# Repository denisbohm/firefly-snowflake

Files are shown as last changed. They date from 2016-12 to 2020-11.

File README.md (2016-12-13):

# firefly-snowflake
Firefly Design LLC - Snowflake Christmas Ornament

The snowflake is a Christmas tree ornament with RGB LEDs that light up in various ways.  It has a rechargeable battery (via micro USB port) and it is controllable via BLE via a Swift app.

This repository has all the files to create a snowflake Christmas ornament.  This includes 3D mechanical files to create the plastic parts, Eagle schematics & layout for the PCBA, PCBA firmware, and Swift App source files.

To compile the firmware you need the Nordic nRF5 SDK 12 and Firefly Ice Firmware.  On macOS:

    $ git clone https://github.com/denisbohm/firefly-snowflake.git
    $ cd firefly-snowflake/firmware
    $ git clone https://github.com/denisbohm/firefly-ice-firmware.git
    $ curl https://www.nordicsemi.com/eng/nordic/download_resource/54291/51/54256290 -o nRF5_SDK_12.zip
    $ unzip nRF5_SDK_12.zip -d nRF5_SDK_12

See [Firefly Design LLC](http://fireflydesign.com) for information on the open source Firefly Design repositories.

## Copyright and License
Copyright 2016 Firefly Design LLC / Denis Bohm



This work is licensed under [Creative Commons Attribution 4.0 International](https://licensebuttons.net/l/by/4.0/88x31.png).

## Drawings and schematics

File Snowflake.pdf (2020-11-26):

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

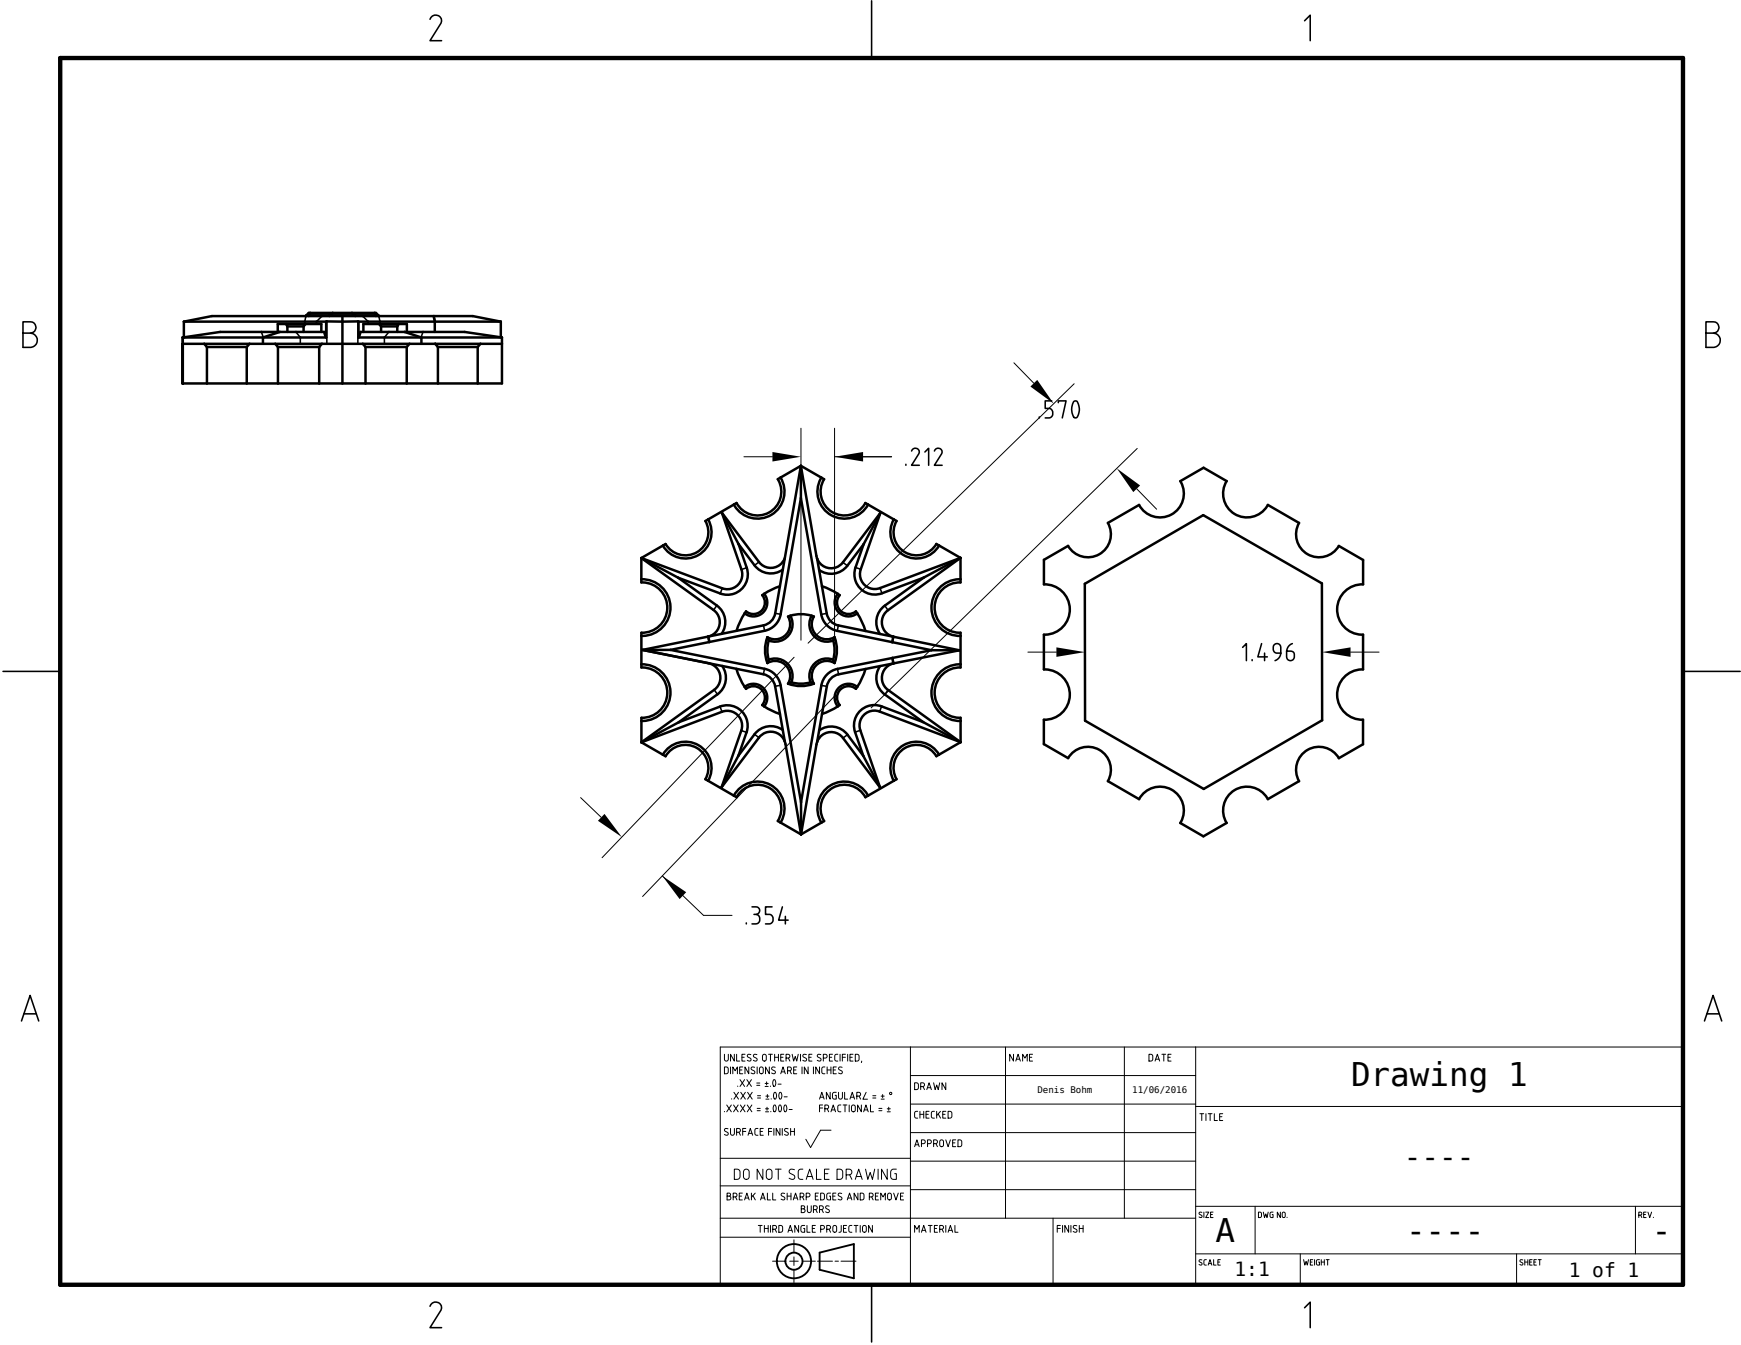
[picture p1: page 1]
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

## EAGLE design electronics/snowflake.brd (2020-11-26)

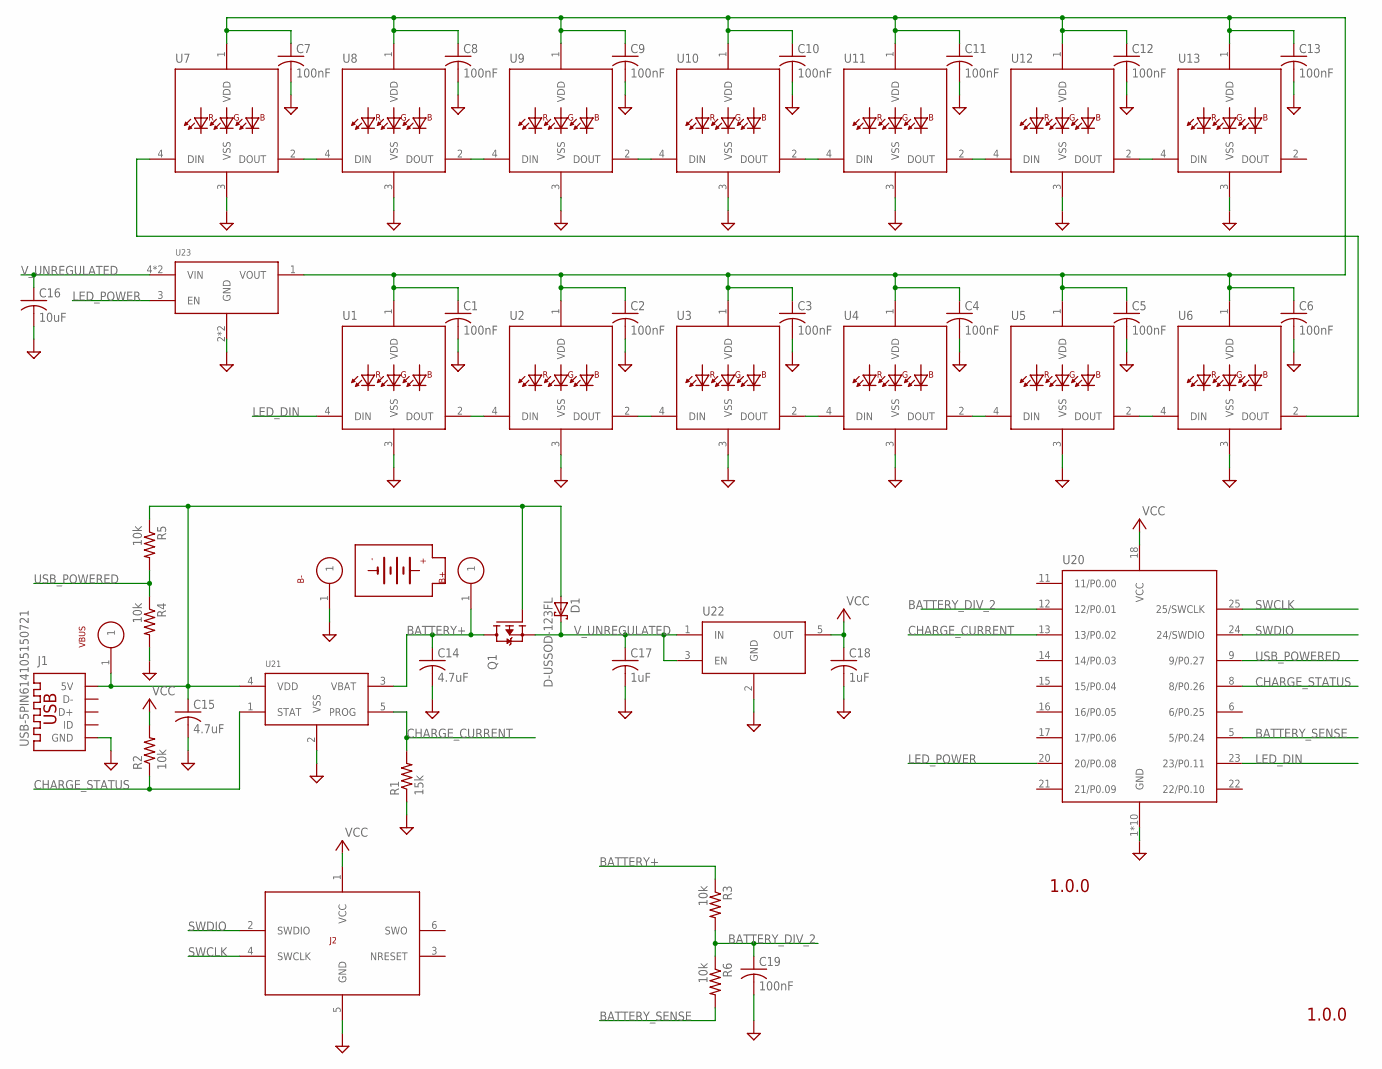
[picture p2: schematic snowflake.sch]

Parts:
B1: BATTERY_SHAPEDTP401525; DTP401525
B+: TARGET-PINWP-28AWG; WP-28AWG
B-: TARGET-PINWP-28AWG; WP-28AWG
C1, C2, C3, C4, C5, C6, C7, C8, C9, C10, C11, C12, C13, C19: 100nF; C0805
C14, C15: 4.7uF; C0805
C16: 10uF; C0805
C17, C18: 1uF; C0805
D1: D-USSOD-123FL; SOD-123FL
J1: USB-5PIN614105150721; 614105150721
J2: TC2030-SWD; TC2030-MCP-NL
Q1: FET-PSOT-23-3; SOT-23-3
R1: 15k; R0805
R2, R3, R4, R5, R6: 10k; R0805
U1, U2, U3, U4, U5, U6, U7, U8, U9, U10, U11, U12, U13: WS2812B
U20: BMD-200
U21: MCP73832SOT-23-5; SOT-23-5
U22: ADP160; TSOT-5
U23: TPS22929D; SOT-23-6
VBUS: TARGET-PIN; TARGET-PIN-1MM

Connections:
BATTERY+: B+.1, C14.1, Q1.3 (D), R3.1, U21.3 (VBAT)
BATTERY_DIV_2: C19.1, R3.2, R6.1, U20.12 (12/P0.01)
BATTERY_SENSE: R6.2, U20.5 (5/P0.24)
CHARGE_CURRENT: R1.2, U20.13 (13/P0.02), U21.5 (PROG)
CHARGE_STATUS: R2.1, U20.8 (8/P0.26), U21.1 (STAT)
GND: B-.1, C1.2, C2.2, C3.2, C4.2, C5.2, C6.2, C7.2, C8.2, C9.2, C10.2, C11.2, C12.2, C13.2, C14.2, C15.2, C16.2, C17.2, C18.2, C19.2, J1.5 (GND), J2.5 (GND), R1.1, R4.2, U1.3 (VSS), U2.3 (VSS), U3.3 (VSS), U4.3 (VSS), U5.3 (VSS), U6.3 (VSS), U7.3 (VSS), U8.3 (VSS), U9.3 (VSS), U10.3 (VSS), U11.3 (VSS), U12.3 (VSS), U13.3 (VSS), U20.1 (GND), U20.2 (GND), U20.3 (GND), U20.4 (GND), U20.7 (GND), U20.10 (GND), U20.19 (GND), U20.26 (GND), U20.27 (GND), U20.28 (GND), U21.2 (VSS), U22.2 (GND), U23.2 (GND), U23.5 (GND)
LED_DIN: U1.4 (DIN), U20.23 (23/P0.11)
LED_POWER: U20.20 (20/P0.08), U23.3 (EN)
unnamed: U8.2 (DOUT), U9.4 (DIN)
unnamed: U10.2 (DOUT), U11.4 (DIN)
unnamed: U12.2 (DOUT), U13.4 (DIN)
unnamed: U1.2 (DOUT), U2.4 (DIN)
unnamed: U3.2 (DOUT), U4.4 (DIN)
unnamed: U5.2 (DOUT), U6.4 (DIN)
unnamed: U7.2 (DOUT), U8.4 (DIN)
unnamed: U9.2 (DOUT), U10.4 (DIN)
unnamed: U11.2 (DOUT), U12.4 (DIN)
unnamed: U6.2 (DOUT), U7.4 (DIN)
unnamed: U2.2 (DOUT), U3.4 (DIN)
unnamed: U4.2 (DOUT), U5.4 (DIN)
unnamed: C15.1, D1.A, J1.1 (5V), Q1.1 (G), R5.1, U21.4 (VDD), VBUS.1
SWCLK: J2.4 (SWCLK), U20.25 (25/SWCLK)
SWDIO: J2.2 (SWDIO), U20.24 (24/SWDIO)
USB_POWERED: R4.1, R5.2, U20.9 (9/P0.27)
VCC: C18.1, J2.1 (VCC), R2.2, U20.18 (VCC), U22.5 (OUT)
VCC1: C1.1, C2.1, C3.1, C4.1, C5.1, C6.1, C7.1, C8.1, C9.1, C10.1, C11.1, C12.1, C13.1, U1.1 (VDD), U2.1 (VDD), U3.1 (VDD), U4.1 (VDD), U5.1 (VDD), U6.1 (VDD), U7.1 (VDD), U8.1 (VDD), U9.1 (VDD), U10.1 (VDD), U11.1 (VDD), U12.1 (VDD), U13.1 (VDD), U23.1 (VOUT)
V_UNREGULATED: C16.1, C17.1, D1.C, Q1.2 (S), U22.1 (IN), U22.3 (EN), U23.4 (VIN), U23.6 (VIN)

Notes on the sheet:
1.0.0

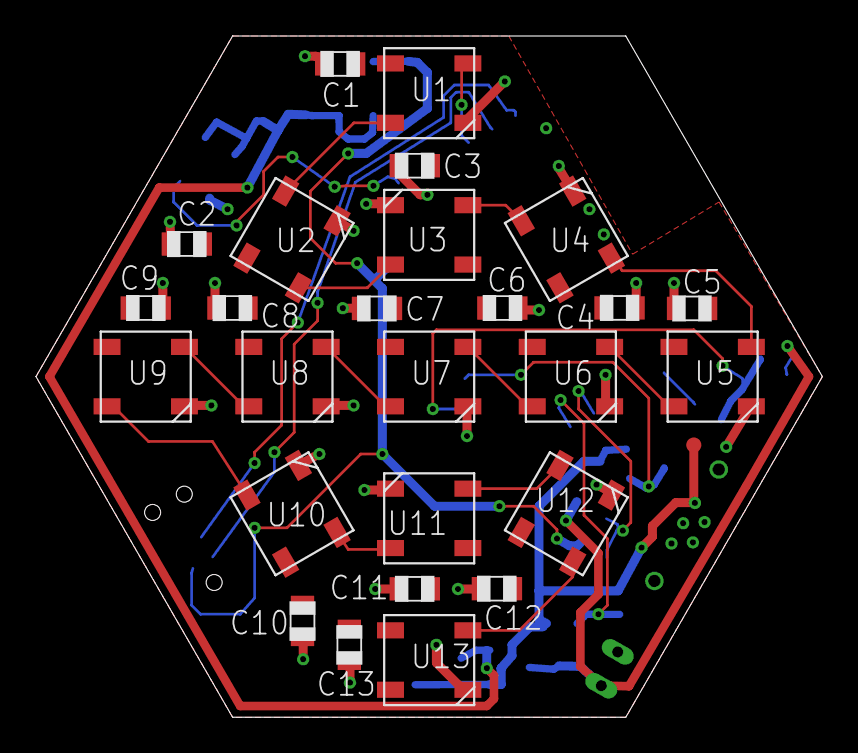
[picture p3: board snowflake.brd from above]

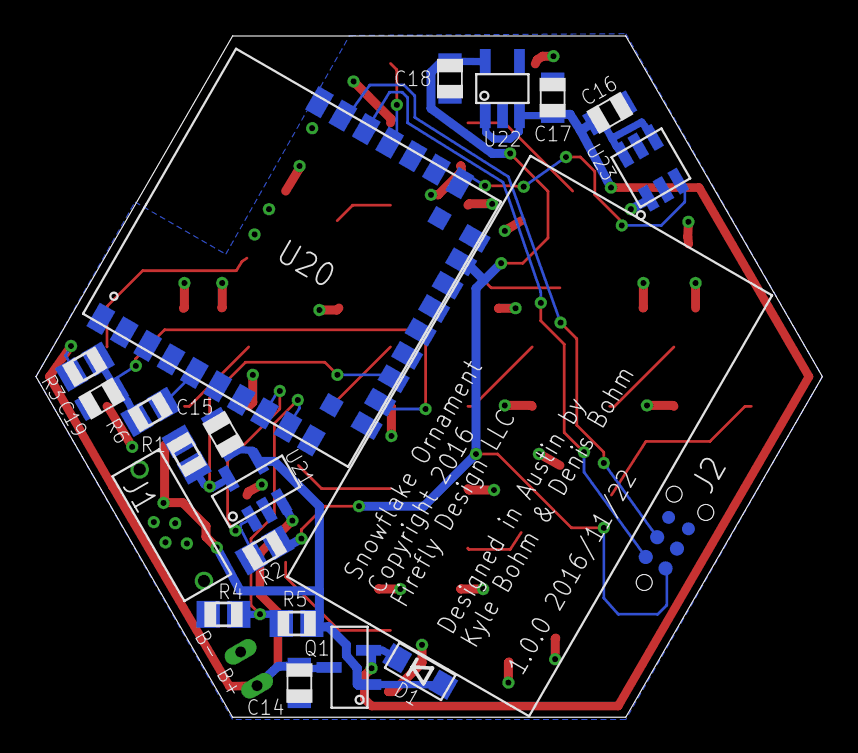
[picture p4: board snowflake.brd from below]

Board: 2 copper layers, 43.7 x 37.8 mm, 50 parts (23 on the bottom side), 27 nets.

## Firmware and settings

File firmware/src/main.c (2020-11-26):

#include "fd_api.h"
#include "fd_hal_app.h"
#include "fd_hal_ble.h"
#include "fd_hal_delay.h"
#include "fd_hal_gpio.h"
#include "fd_log.h"

#include "fd_snowflake.h"
#include "fd_breathe_animation.h"
#include "fd_WS2812B.h"

#include <stdbool.h>
#include <stdint.h>

const fd_snowflake_program_t *fd_snowflake_program;

bool fd_snowflake_leds_powered;

uint32_t fd_snowflake_instruction_index;
fd_snowflake_operation_t fd_snowflake_operation;

uint32_t fd_snowflake_illuminate_step;
uint32_t fd_snowflake_illuminate_grbz_index;
uint32_t fd_snowflake_illuminate_step_count;

uint32_t fd_snowflake_pause_steps_remaining;

uint32_t fd_snowflake_sleep_seconds_remaining;

void fd_hal_ble_characteristic_value_change(uint16_t uuid, uint8_t *data, uint16_t length) {
}

void fd_hal_ble_gap_evt_connected(void) {
}

void fd_hal_ble_gap_evt_disconnected(void) {
}

void fd_hal_ble_gap_evt_tx_complete(uint8_t count) {
}

void fd_snowflake_step(void);

fd_hal_ble_time_slot_callback_result_t fd_snowflake_time_slot(void) {
    switch (fd_snowflake_operation) {
        case fd_snowflake_operation_illuminate: { // 16-bit step count, 16-bit starting grbz index
            const uint32_t *grbzs = &fd_snowflake_program->grbzs[fd_snowflake_illuminate_grbz_index];
            fd_WS2812B_data(grbzs, 13);
            fd_snowflake_illuminate_grbz_index += 13;

            if (++fd_snowflake_illuminate_step >= fd_snowflake_illuminate_step_count) {
                fd_snowflake_step();
            }
        } break;
        case fd_snowflake_operation_pause: { // 16-bit step count (holds current LED colors)
            if (fd_snowflake_pause_steps_remaining-- == 0) {
                fd_snowflake_step();
            }
        } break;
        default:
            fd_log_assert_fail("unexpected operation");
    }
    return fd_hal_ble_time_slot_callback_result_continue;
}

void fd_snowflake_power_on_leds(void) {
    // turn on LED power and wait for rail to come up
    fd_snowflake_leds_powered = true;
    fd_hal_gpio_on(FD_SNOWFLAKE_PIN_LED_POWER);
    fd_hal_delay_us(500);
}

void fd_snowflake_power_off_leds(void) {
    fd_hal_gpio_off(FD_SNOWFLAKE_PIN_LED_POWER);
    fd_snowflake_leds_powered = false;
}

void fd_snowflake_start_time_slots(void) {
    if (fd_snowflake_leds_powered) {
        return;
    }

    fd_snowflake_power_on_leds();

#if USE_WITH_SOFTDEVICE == 1
    // start LED animation time slots
    //
    // 50 ms (20 Hz) between LED updates
    // 50 us to send BRG values to all LEDs, plus 50 us to reset the LED communication slot
    // !!! 1000 us seems to be lowest value Nordic time slot SDK will accept (or hello hard fault) -denis
    bool result = fd_hal_ble_time_slot_initialize(50000, 1000, fd_snowflake_time_slot);
    fd_log_assert(result);
#endif
}

void fd_snowflake_stop_time_slots(void) {
    if (!fd_snowflake_leds_powered) {
        return;
    }

#if USE_WITH_SOFTDEVICE == 1
    fd_hal_ble_time_slot_close();
#endif

    fd_snowflake_power_off_leds();
}

void fd_snowflake_illuminate(uint32_t step_count, uint32_t grbz_index) {
    fd_snowflake_illuminate_step = 0;
    fd_snowflake_illuminate_grbz_index = grbz_index;
    fd_snowflake_illuminate_step_count = step_count;

    fd_snowflake_start_time_slots();
}

void fd_snowflake_pause(uint32_t step_count) {
    fd_snowflake_pause_steps_remaining = step_count;
}

void fd_snowflake_sleep_done(void) {
    fd_snowflake_step();
}

void fd_snowflake_sleep(uint32_t seconds) {
    fd_snowflake_stop_time_slots();

    fd_hal_app_timer_start(seconds * 1000, fd_snowflake_sleep_done);

    fd_snowflake_sleep_seconds_remaining = seconds;
}

void fd_snowflake_restart(void) {
    fd_snowflake_instruction_index = 0;
    fd_snowflake_illuminate_step = 0;
    fd_snowflake_illuminate_grbz_index = 0;
    fd_snowflake_illuminate_step_count = 0;
    fd_snowflake_pause_steps_remaining = 0;
    fd_snowflake_sleep_seconds_remaining = 0;

    fd_snowflake_step();
}

uint32_t fd_snowflake_next_operand(void) {
    uint32_t b0 = fd_snowflake_program->instructions[fd_snowflake_instruction_index++];
    uint32_t b1 = fd_snowflake_program->instructions[fd_snowflake_instruction_index++];
    return (b1 << 8) | b0;
}

void fd_snowflake_step(void) {
    fd_snowflake_operation = fd_snowflake_program->instructions[fd_snowflake_instruction_index++];
    switch (fd_snowflake_operation) {
        case fd_snowflake_operation_illuminate: { // 16-bit step count, 16-bit starting grbz index
            uint32_t step_count = fd_snowflake_next_operand();
            uint32_t grbz_index = fd_snowflake_next_operand();
            fd_snowflake_illuminate(step_count, grbz_index);
        } break;
        case fd_snowflake_operation_pause: { // 16-bit step count (holds current LED colors)
            uint32_t step_count = fd_snowflake_next_operand();
            fd_snowflake_pause(step_count);
        } break;
        case fd_snowflake_operation_sleep: { // 16-bit seconds (turns off power to LEDs, etc)
            uint32_t seconds = fd_snowflake_next_operand();
            fd_snowflake_sleep(seconds);
        } break;
        case fd_snowflake_operation_restart: // jump back to first operation
            fd_snowflake_restart();
        default: {
        } break;
    }
}

void fd_snowflake_start(const fd_snowflake_program_t *program) {
    fd_snowflake_program = program;
    fd_snowflake_restart();
}

int main(void) {
    fd_hal_gpio_initialize();
    fd_snowflake_leds_powered = false;
    fd_WS2812B_initialize(FD_SNOWFLAKE_PIN_LED_DIN);

    fd_hal_app_initialize();

#if USE_WITH_SOFTDEVICE == 1
    uint8_t service_base[16] = {0xB3, 0x49, 0x1D, 0x48, 0x47, 0x86, 0x79, 0x97, 0x07, 0x48, 0x3E, 0x55, 0x00, 0x00, 0x7F, 0x57};
    fd_hal_ble_configuration_t configuration = {
        .hardware_revision = {
            .major = 1,
            .minor = 0,
            .patch = 0,
        },
        .firmware_revision = {
            .major = 1,
            .minor = 0,
            .patch = 0,
        },
        .manufacturer = "Firefly Design LLC",
        .model = "Snowflake",
        .serial_number = "0000",
        .device_name = "flake-01",
        .service_base = service_base,
        .service_uuid = 0xB8B4,
    };
    fd_hal_ble_initialize(&configuration);
    fd_api_initialize();
    fd_api_initialize_ble();
    fd_hal_ble_start_advertising();
#endif

#if USE_WITH_SOFTDEVICE == 1
    fd_snowflake_start(&fd_breathe_program);
    while (true) {
        fd_api_process();
        fd_hal_app_dispatch_and_wait();
    }
#else
    fd_snowflake_start(&fd_breathe_program);
    while (true) {
        if (fd_snowflake_leds_powered) {
            fd_snowflake_time_slot();
        }
        fd_hal_delay_ms(50);
        app_sched_execute();
        // !!! need to do something about timers...
    }
#endif
}

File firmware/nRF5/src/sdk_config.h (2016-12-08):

#ifndef SDK_CONFIG_H
#define SDK_CONFIG_H

#ifdef USE_APP_CONFIG
#include "app_config.h"
#endif

// add configuration here

#define GPIOTE_ENABLED 1
#define GPIOTE_CONFIG_IRQ_PRIORITY 3
#define GPIOTE_CH_NUM 4
#define GPIOTE_CONFIG_NUM_OF_LOW_POWER_EVENTS 4

#define APP_GPIOTE_ENABLED 1

#define APP_TIMER_ENABLED 1

#define APP_SCHEDULER_ENABLED 1

#define BLE_DIS_ENABLED 1

#endif

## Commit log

2016-11-21 added revision number to schematic and layout
    [snowflake.brd, snowflake.sch]
2016-11-22 update silk
    [snowflake.brd]
2016-12-08 communication to LED controller working
2016-12-24 25uA with LEDs off
2020-11-26 misc tweaks
    [snowflake.brd, snowflake.sch]
2020-12-14 simulator update; new led animation option

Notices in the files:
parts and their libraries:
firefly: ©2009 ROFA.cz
